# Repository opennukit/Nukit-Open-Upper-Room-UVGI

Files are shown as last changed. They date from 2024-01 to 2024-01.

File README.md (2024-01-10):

# About Nukit Open Upper Room UVGI
Nukit Open Upper-Room UVGI (Ultraviolet Germicidal Irradiation) fixtures are Open Hardware devices for researching and developing localized Upper-Room UVGI solutions. They are not a DIY project and should only be used with UVC lights by qualified professionals. If you would like to learn about Upper-Room UVGI you can use them with safe, readily available white lights and a lux meter. 

Qualified professionals will need a UVC meter that measures 254nm to 0.01 mW/cm2 resolution, a protective face shield that has UV blocking characteristics verified by that UVC meter, long sleeves, and lightweight gloves.

If you attempt to deploy or research UVGI without the above equipment, you will likely become a news story that further harms this potentially life-saving technology. 

[Geneseo faculty say an experiment using ultraviolet light to kill COVID-19 damaged their eyes](https://www.wxxinews.org/local-news/2022-04-14/geneseo-faculty-say-uv-c-light-to-target-covid-damaged-their-eyes)

[Doctors warn about eye damage from UV lights to kill the coronavirus](https://www.nbcnews.com/health/health-news/doctors-warn-about-eye-damage-uv-lights-kill-coronavirus-n1249009)

[Bored Ape creator says UV lights at ApeFest burned attendees’ eyes and skin](https://arstechnica.com/health/2023/11/bored-ape-creator-says-uv-lights-at-apefest-burned-attendees-eyes-and-skin/)

**General Guidelines**
---
There are reference Nukit Open Upper-Room UVGI fixtures available for hand tools, lasercutting, 3D printing, and sheet metal fabrication. All are designed to be adapted to local materials and conditions by local engineers and researchers. [Read more about the project here.](https://github.com/opennukit/Nukit-Open-Upper-Room-UVGI/blob/e78abfc1034ac28526194f0c7dd7b21da4218601/Nukit%20Open%20Upper%20Room%20UVGI%20Project%20Description/OSH-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)

For an excellent overview of Upper-Room UVGI, see Joey Fox's article [Intro to Upper-Room UVGI](https://itsairborne.com/intro-to-upper-room-uvgi-a36e00862c04)

There are videos featuring the fabrication and installation of Open Upper-Room UVGI [here](https://youtu.be/QSnUce9xdNo) and [here](https://youtu.be/VVzKQwjtzhc). However, once again, this is not a DIY project, and non-professional experimentation should be done with safe, white light.

The following two guides should be considered a prerequisite for any Open Upper-Room UVGI fabrication, installation, or experimentation.

[Guidelines for the Application of Upper-Room Ultraviolet Germicidal Irradiation for Preventing Transmission of Airborne Contagion—Part I- Basic Principles](https://www.mediafire.com/file/c3c6aij5ctm65wk/Guidelines_for_the_Application_of_Upper-Room_Ultraviolet_Germicidal_Irradiation_for_Preventing_Transmission_of_Airborn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)

[Guidelines for the Application of Upper-Room Ultraviolet Germicidal Irradiation for Preventing Transmission of Airborne Contagion—Part II- Design and Operation Guidance](https://www.mediafire.com/file/8tyhdqi13e3368i/Guidelines_for_the_Application_of_Upper-Room_Ultraviolet_Germicidal_Irradiation_for_Preventing_Transmission_of_Airborn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)

(Sorry for the MediaFire link, please let us know if you are willing to host PDFs with potential DMCA issues on a private server)

This project was funded by a grant from Vitalik Buterin's Balvi Fund.

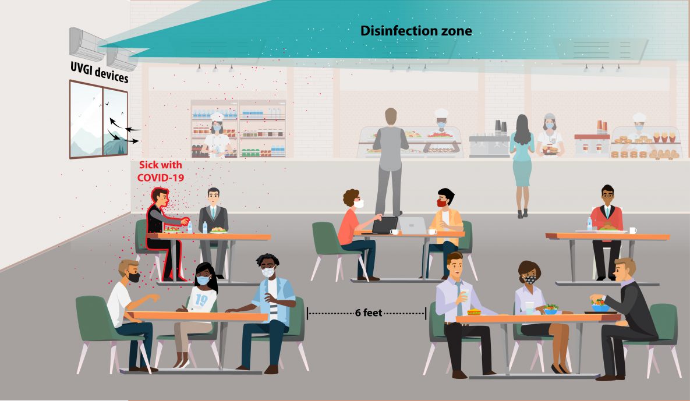
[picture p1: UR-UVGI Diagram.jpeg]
Upper-Room UVGI Diagram


**License**
---
All Nukit Open Upper Room UVGI fixtures are released under GPL-3. 
https://www.gnu.org/licenses/gpl-3.0.en.html

TLDR;
(For our purposes, “software” refers to the digital files used to make Nukit Open Upper Room UVGI fixtures)

1. Anyone can copy, modify and distribute this software.
2. You have to include the license and copyright notice with each and every distribution.
3. You can use this software privately.
4. You can use this software for commercial purposes.
5. If you dare build your business solely from this code, you risk open-sourcing the whole code base.
6. If you modify it, you have to indicate changes made to the code.
7. Any modifications of this code base MUST be distributed with the same license, GPLv3.
8. This software is provided without warranty.
9. The software author or license can not be held liable for any damages inflicted by the software.

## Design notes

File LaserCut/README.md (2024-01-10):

# Laser-Cut Nukit Open Upper-Room UVGI

Laser-Cut Nukit Open Upper-Room UVGI fixtures are designed to be made on laser diode or CO2 laser cutters, anywhere in the world, from local materials. They cost a fraction of the price of commercial UR-UVGI fixtures and can be customized to suit local conditions. They do, however, require careful installation by trained technicians. Once that's done, they are extremely effective, safe, and inexpensive to operate.

**Pendent Style- Wood**
---
This is a very powerful, very low-cost mitigation tool that, with appropriate training, can be rapidly deployed in disaster areas, field hospitals, refugee camps, commandeered auditoriums, and gymnasiums. Any place that is large, crowded, has high ceilings and is high risk for aerosol transmission. 

When cut out of 2mm plywood the cost is about 8USD. Combined with an Ikea [STRÅLA](https://www.ikea.com/us/en/p/strala-cord-set-white-90371505/) (5USD) or [HEMMA](https://www.ikea.com/us/en/p/hemma-cord-set-white-50386580/) (10USD) and a UVC CFL bulb there is very little light leakage below the fixture. The irradiation field is 360° and 3° down (see diagram). As such, very little light is wasted, and they are extremely efficient.

At and above ahorizontal plane the output level is approximately:  
16μW/cm2 @ 1m  
7μW/cm2 @ 1.5m  
4μW/cm2 @ 2m

Diagram of safe versus germicidal zones:
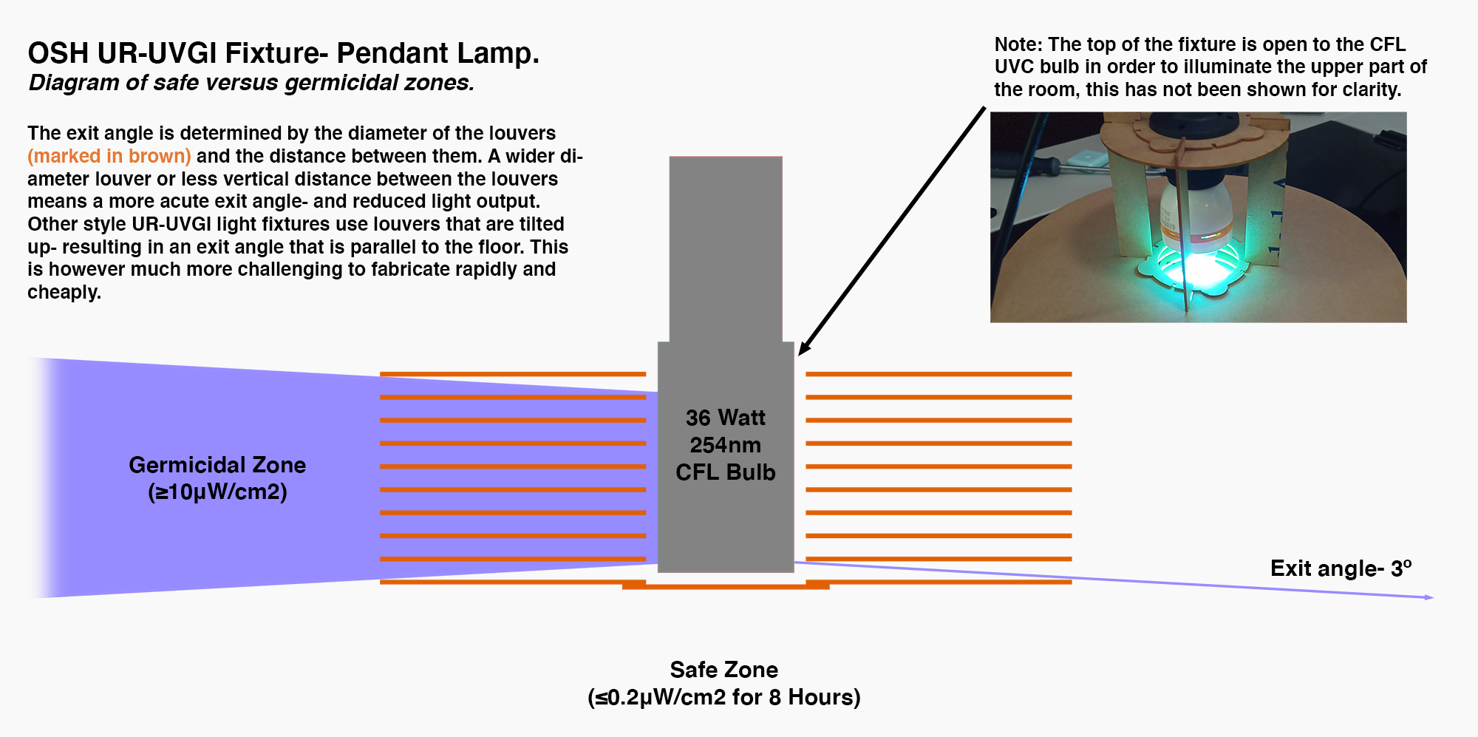
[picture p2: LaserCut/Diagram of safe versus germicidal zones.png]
Diagram of safe versus germicidal zones


[This version is the best one to start with](https://github.com/opennukit/Nukit-Open-Upper-Room-UVGI/tree/main/LaserCut/Nukit%20Open%20Upper%20Room%20UVGI%20Pendent%20Fixture/Nukit%20Open%20Upper%20Room%20UVGI%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), as it is nested and shippable. Secures with zip-ties, forming an extremely robust solid block that stacks and stands up well to rough handling. There is a somewhat heavier [1/8th inch version here](https://github.com/opennukit/Nukit-Open-Upper-Room-UVGI/tree/main/LaserCut/Nukit%20Open%20Upper%20Room%20UVGI%20Pendent%20Fixture/Nukit%20Open%20Upper%20Room%20UVGI%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) that will require more care in hanging but is easier to make in North America.

The assembly instructions are [here](https://github.com/opennukit/Nukit-Open-Upper-Room-UVGI/blob/main/LaserCut/Nukit%20Open%20Upper%20Room%20UVGI%20Pendent%20Fixture/Nukit%20Open%20Upper%20Room%20UVGI%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)

Note- coiled E27 UVC CFL bulbs have become difficult to find, but this fixture design can accommodate the more easy-to-source [long and straight E27 UVC CFL bulbs](https://www.amazon.com/coospider-repta-Sanitizer-Germicidal-Replacement-Disinfection/dp/B0CG39F65Z/) simply by adding additional layers of louvers. (NOTE: DO NOT USE UVC LAMPS UNLESS YOU ARE A QUALIFIED PROFESSIONAL WITH A UVC METER- USE WHITE LIGHTS FOR TESTING)

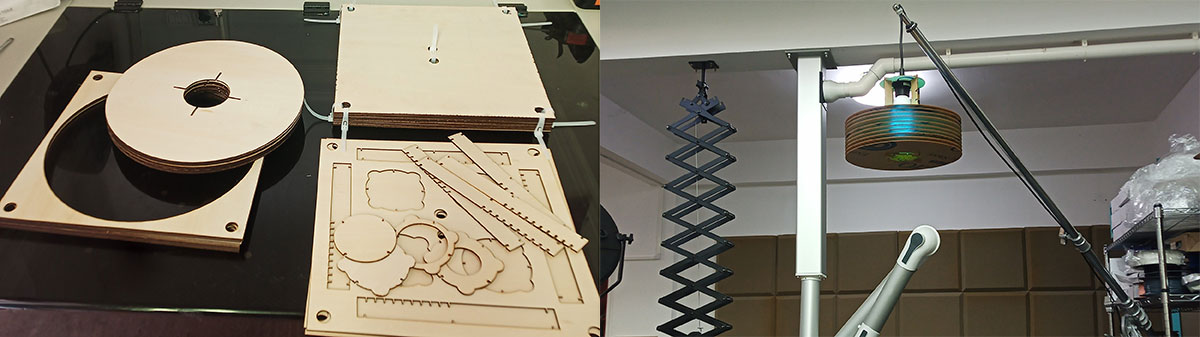
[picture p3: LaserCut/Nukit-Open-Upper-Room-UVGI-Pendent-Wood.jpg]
Laser-Cut Nukit Open Upper Room UVGI Pendent Wood


**Wall-Mount Style- Wood**
---
This style has a more tightly controlled output than the above pendent-style lamp, making it much less powerful but also far easier and safer to install. Using aluminum tape inside the box will greatly improve its efficiency. It uses [M5 threaded rod](https://www.mcmaster.com/products/threaded-rods/thread-size~m5/metric-18-8-stainless-steel-threaded-rods/), [M5 thumb nuts](https://www.amazon.com/uxcell-Knurled-Thumb-Nuts-Stainless/dp/B07WMQL8VX) (can be substituted for imperial sizes depending on local cost and availability), and two [6W T5 mercury vapor UVC lamps](https://www.amazon.com/UV-Sanitizer-253-7nm-wavelength-Bathroom/dp/B0B5CV9PB5). The fixture can easily be extended to accommodate any length of T5 fixture up to 150cm. (NOTE: DO NOT USE UVC LAMPS UNLESS YOU ARE A QUALIFIED PROFESSIONAL WITH A UVC METER- USE WHITE LIGHTS FOR TESTING)

[This version is the best one to start with](https://github.com/opennukit/Nukit-Open-Upper-Room-UVGI/tree/main/LaserCut/Nukit%20Open%20Upper%20Room%20UVGI%20Wall%20Fixture/Nukit%20Open%20Upper%20Room%20UVGI%20(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), as it is nested and shippable. Secures with zip-ties, forming an extremely robust solid block that stacks and stands up well to rough handling. 

The assembly instructions are [here](https://github.com/opennukit/Nukit-Open-Upper-Room-UVGI/tree/main/LaserCut/Nukit%20Open%20Upper%20Room%20UVGI%20Wall%20Fixture/Nukit%20Open%20Upper%20Room%20UVGI%20(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)

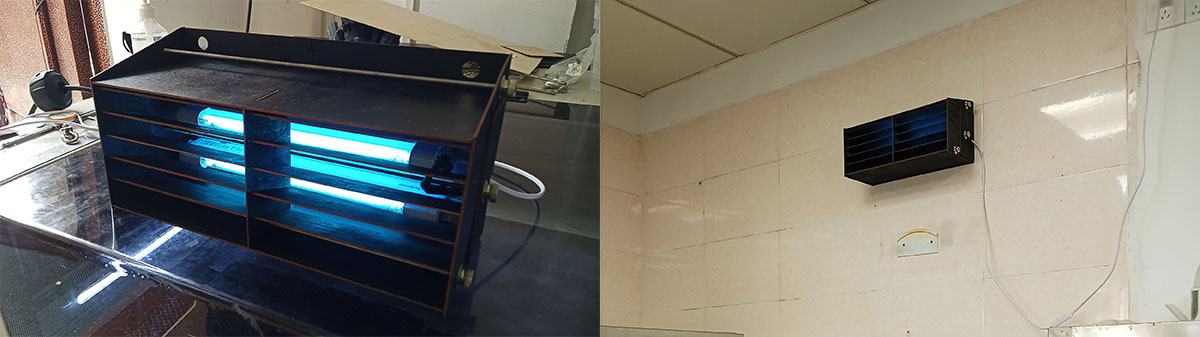
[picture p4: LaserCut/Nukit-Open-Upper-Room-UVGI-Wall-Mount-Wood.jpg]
Laser-Cut Nukit Open Upper Room UVGI Wall-Mount-Wood


**Wall-Mount Style- Metal**
---
An all-metal version of the Nukit Open Upper Room UVGI Wall-Mount fixture. It is designed for local manufacturing and commercial deployment in any country. It can be made in most sheet metal shops equipped with laser or waterjet cutters for a fraction of the cost of importing UR-UVGI devices from overseas.

[You can download the plans here.](https://github.com/opennukit/Nukit-Open-Upper-Room-UVGI/tree/main/LaserCut/Nukit%20Open%20Upper%20Room%20UVGI%20Wall%20Fixture/Nukit%20Open%20Upper%20Room%20UVGI%20W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)

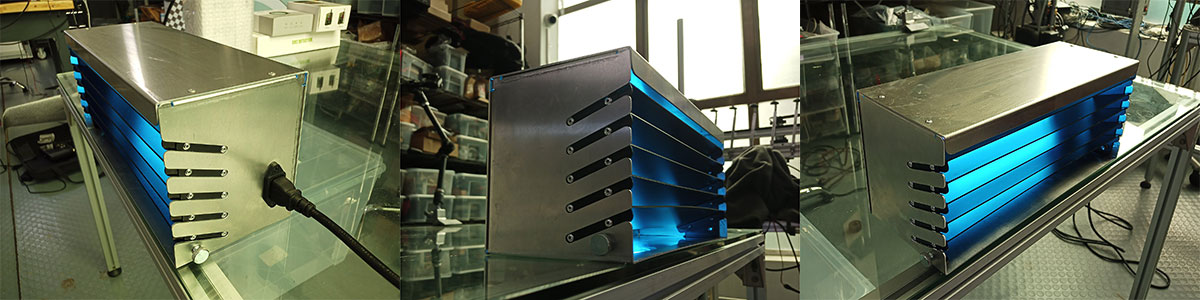
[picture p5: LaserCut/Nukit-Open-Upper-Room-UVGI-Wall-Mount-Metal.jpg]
Laser-Cut Nukit Open Upper Room UVGI Wall-Mount-Metal


**License**
---
All Nukit Open Air Purifiers are released under GPL-3. 
https://www.gnu.org/licenses/gpl-3.0.en.html

TLDR;
(For our purposes, “software” refers to the digital files used to make Nukit Open Air Purifiers)

1. Anyone can copy, modify and distribute this software.
2. You have to include the license and copyright notice with each and every distribution.
3. You can use this software privately.
4. You can use this software for commercial purposes.
5. If you dare build your business solely from this code, you risk open-sourcing the whole code base.
6. If you modify it, you have to indicate changes made to the code.
7. Any modifications of this code base MUST be distributed with the same license, GPLv3.
8. This software is provided without warranty.
9. The software author or license can not be held liable for any damages inflicted by the software.

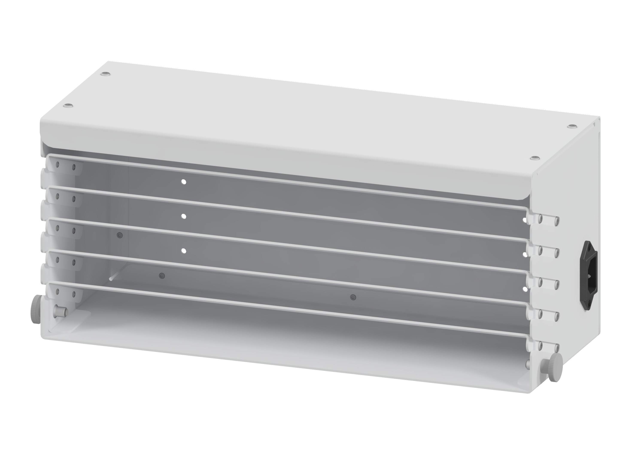
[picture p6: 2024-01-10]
LaserCut/Nukit Open Upper Room UVGI Wall Fixture/Nukit Open Upper Room UVGI Wall Fixture 1.6mm Aluminum/Nukit Open Upper Room UVGI Wall Fixture 1.6mm Aluminum v1.png

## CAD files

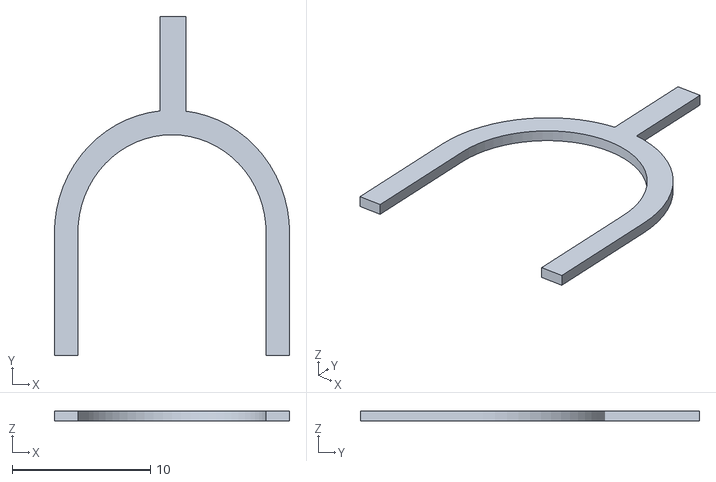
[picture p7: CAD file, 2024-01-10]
LaserCut/Nukit Open Upper Room UVGI Pendent Fixture/UVGI-Assembly-Tool.stl
17.0 x 24.5 x 0.75

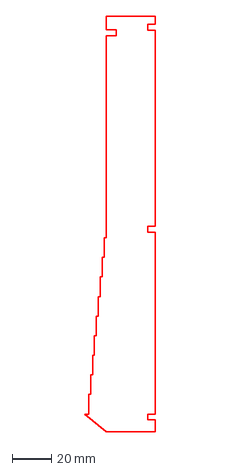
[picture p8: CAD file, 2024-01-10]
LaserCut/Nukit Open Upper Room UVGI Pendent Fixture/Nukit Open Upper Room UVGI Pendent Variants/Nukit Open Upper Room UVGI Pendent Fixture v1 revision c/Nukit Open Upper Room UVGI Pendent Fixture v1 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
36.0 x 212.0 mm

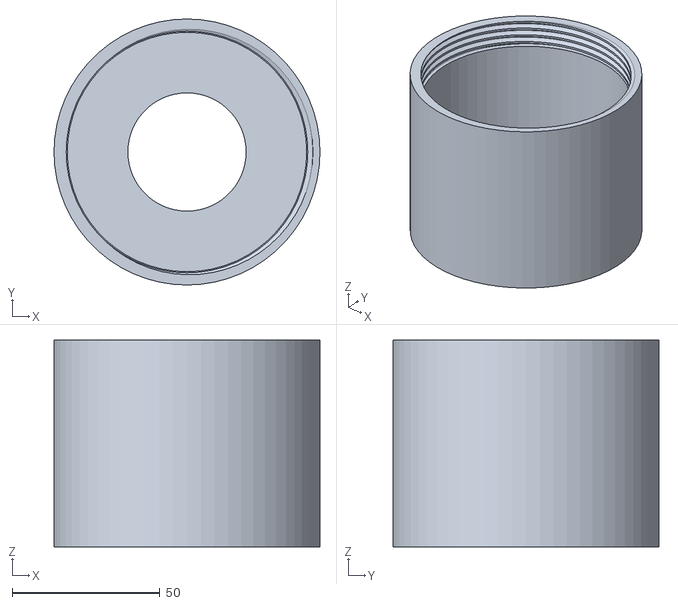
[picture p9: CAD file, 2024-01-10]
3D Printed/UVGI-3DP FDM PETG 220x220x220 Cap.stl
90.0 x 90.0 x 70.0

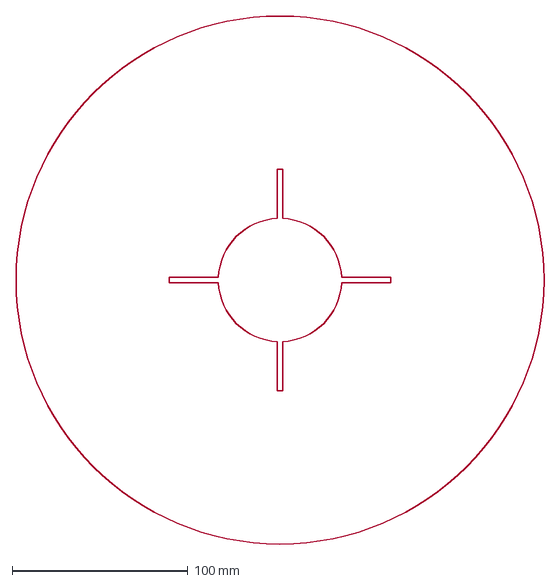
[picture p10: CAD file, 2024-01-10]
LaserCut/Nukit Open Upper Room UVGI Pendent Fixture/Nukit Open Upper Room UVGI Pendent Variants/Nukit Open Upper Room UVGI Pendent Fixture v1 revision c/Nukit Open Upper Room UVGI Pendent Fixture v1 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
300.0 x 300.0 mm

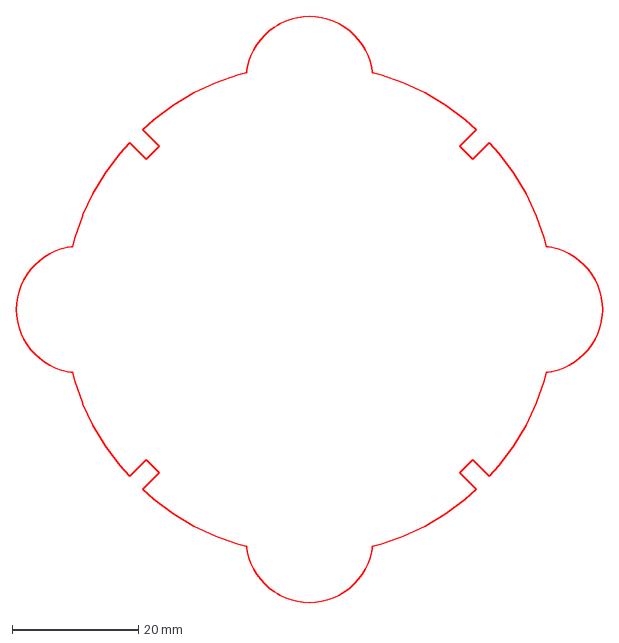
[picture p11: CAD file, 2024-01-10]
LaserCut/Nukit Open Upper Room UVGI Pendent Fixture/Nukit Open Upper Room UVGI Pendent Variants/Nukit Open Upper Room UVGI Pendent Fixture v1 revision c/Nukit Open Upper Room UVGI Pendent Fixture v1 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
92.9 x 92.9 mm

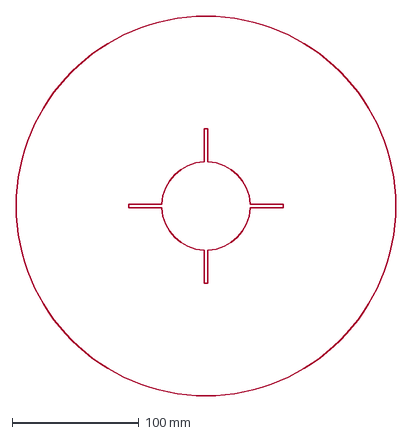
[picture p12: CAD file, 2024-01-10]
LaserCut/Nukit Open Upper Room UVGI Pendent Fixture/Nukit Open Upper Room UVGI Pendent Variants/Nukit Open Upper Room UVGI Pendent Fixture v1 revision c/Nukit Open Upper Room UVGI Pendent Fixture v1 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
300.0 x 300.0 mm

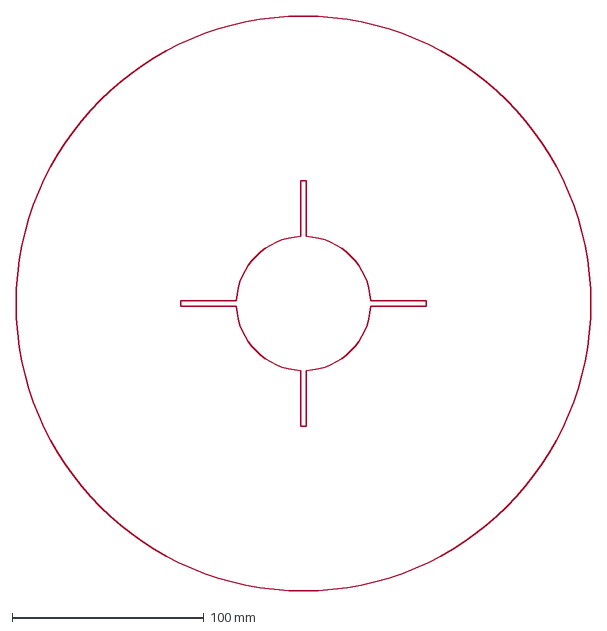
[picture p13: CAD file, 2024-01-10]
LaserCut/Nukit Open Upper Room UVGI Pendent Fixture/Nukit Open Upper Room UVGI Pendent Variants/Nukit Open Upper Room UVGI Pendent Fixture v1 revision c/Nukit Open Upper Room UVGI Pendent Fixture v1 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
300.0 x 300.0 mm

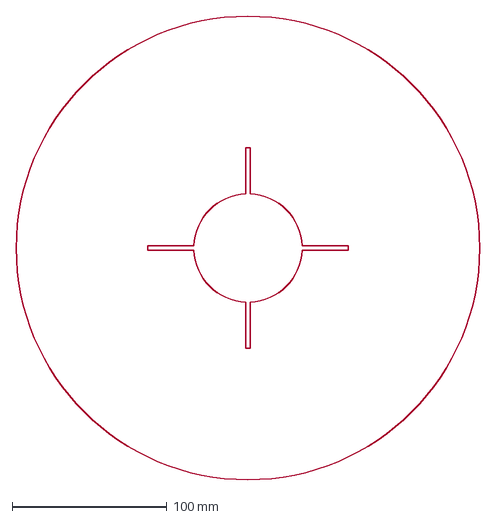
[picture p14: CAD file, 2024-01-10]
LaserCut/Nukit Open Upper Room UVGI Pendent Fixture/Nukit Open Upper Room UVGI Pendent Variants/Nukit Open Upper Room UVGI Pendent Fixture v1 revision c/Nukit Open Upper Room UVGI Pendent Fixture v1 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
300.0 x 300.0 mm

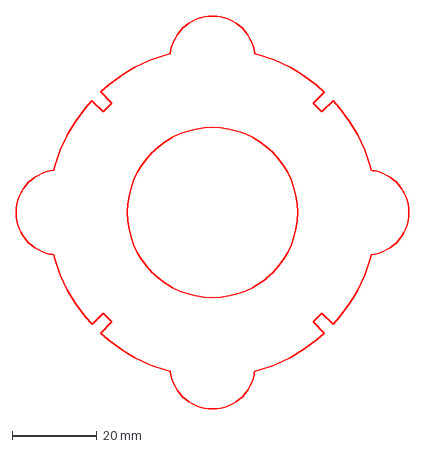
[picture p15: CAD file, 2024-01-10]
LaserCut/Nukit Open Upper Room UVGI Pendent Fixture/Nukit Open Upper Room UVGI Pendent Variants/Nukit Open Upper Room UVGI Pendent Fixture v1 revision c/Nukit Open Upper Room UVGI Pendent Fixture v1 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
92.9 x 92.9 mm

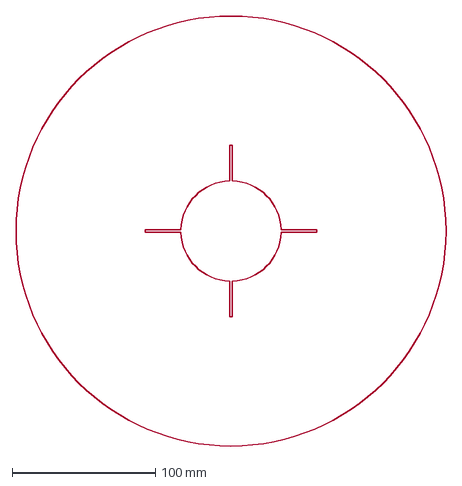
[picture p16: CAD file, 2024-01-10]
LaserCut/Nukit Open Upper Room UVGI Pendent Fixture/Nukit Open Upper Room UVGI Pendent Variants/Nukit Open Upper Room UVGI Pendent Fixture v1 revision c/Nukit Open Upper Room UVGI Pendent Fixture v1 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
300.0 x 300.0 mm

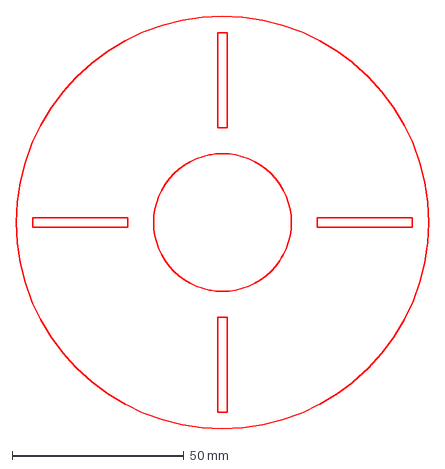
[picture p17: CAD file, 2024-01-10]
LaserCut/Nukit Open Upper Room UVGI Pendent Fixture/Nukit Open Upper Room UVGI Pendent Variants/Nukit Open Upper Room UVGI Pendent Fixture v1 revision c/Nukit Open Upper Room UVGI Pendent Fixture v1 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
120.0 x 120.0 mm

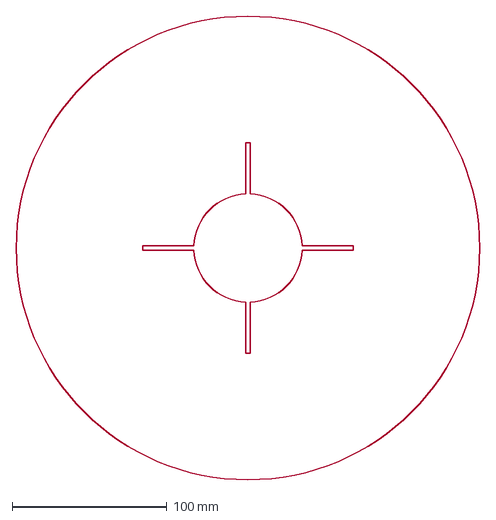
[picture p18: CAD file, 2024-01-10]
LaserCut/Nukit Open Upper Room UVGI Pendent Fixture/Nukit Open Upper Room UVGI Pendent Variants/Nukit Open Upper Room UVGI Pendent Fixture v1 revision c/Nukit Open Upper Room UVGI Pendent Fixture v1 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
300.0 x 300.0 mm

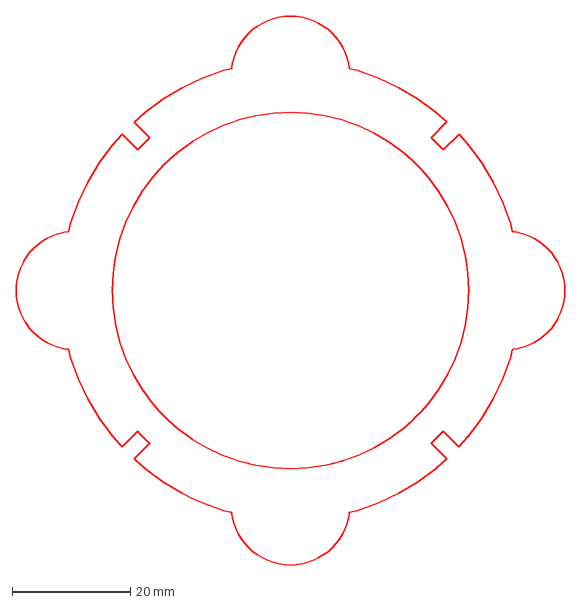
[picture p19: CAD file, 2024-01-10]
LaserCut/Nukit Open Upper Room UVGI Pendent Fixture/Nukit Open Upper Room UVGI Pendent Variants/Nukit Open Upper Room UVGI Pendent Fixture v1 revision c/Nukit Open Upper Room UVGI Pendent Fixture v1 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
92.9 x 92.9 mm

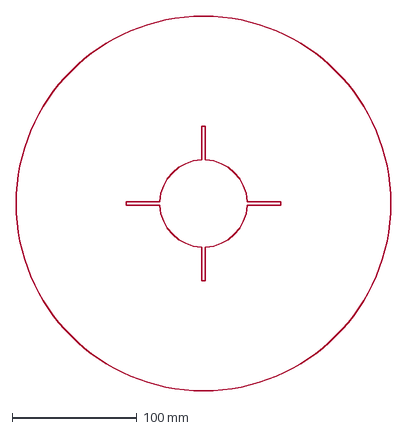
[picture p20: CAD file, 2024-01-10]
LaserCut/Nukit Open Upper Room UVGI Pendent Fixture/Nukit Open Upper Room UVGI Pendent Variants/Nukit Open Upper Room UVGI Pendent Fixture v1 revision c/Nukit Open Upper Room UVGI Pendent Fixture v1 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
300.0 x 300.0 mm

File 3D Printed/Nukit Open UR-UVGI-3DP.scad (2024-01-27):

/* [Model Options] */

Print_Part = "shade"; // ["shade","cap","assembly"]

/* [UV Lampshade] */
Shade_Height = 120;   // [50:400]
Shade_Diameter = 120; // [50:400]
Shade_Bore = 70;      // [20:100]
Base_Height = 2;      // [0:5]

/* [Light Ports] */
Top_Wedge = true; 
Port_X_Count = 44;  // [0:60]
Port_Y_Count = 12;   // [0:30]
Port_Wall = 0.8;      // [0:0.1:5]
Port_Segments = 100; // [5:200]
Port_Angle = 0;     // [-30:45]

/* [Screw Thread] */
Thread_Height = 10;      // [5:20]
Thread_Pitch = 3;        // [1:0.1:5]
Thread_Angle = 30;	    // [20:45]
Thread_Resolution = 60; // [60,120,180]

/* [Screw Cap] */
Cap_Height = 70;        // [10:100]
Cap_Bore = 40;          // [0:100]
Cap_Hole_Count   = 0;   // [0:20]
Cap_Hole_Offset  = 30;  // [0:0.1:100]
Cap_Hole_Size = 4;      // [1:0.1:40]
Cap_Thread_Tolerance = 0.3; // [0:0.1:0.5]

/* [Assembly] */
Cutaway = false;


/* [Hidden] */
Thread_Diameter = Shade_Bore + 15;

use <quickthread.scad> 

if(Print_Part=="shade") {
	lightshade();
} else if(Print_Part=="cap") {
	translate([0,0,Cap_Height]) rotate([180,0,0]) lightshade_cap();
} else if(Print_Part=="dev") {
	if(1) helix();
	if(0) helix_wedge(segments=10);
} else if(Print_Part=="assembly") {
	if(1) difference() {
		color("gold") lightshade();
		if(Cutaway) color("red") translate([0,0,Base_Height+10+0.001]) cube([100,100,120]);
	}

	if(1) translate([0,0,Shade_Height + 0.0]) difference() {
		color("gold") lightshade_cap();
		if(Cutaway) color("red") translate([0,0,-0.001]) cube([Shade_Diameter/2,Shade_Diameter/2,120]);
	}
}


function circle_p(theta) = [cos(theta),sin(theta),0];

module helix(or=50,ir=20,h=40,wall=2,wrap=0.2,segments=50) {
	rz = (or-ir)*sin(Port_Angle); // radial height change
	base = (Port_Angle<0) ? rz : 0;
	zh = h + (Top_Wedge ? abs(base) : abs(rz));
	ai = 360*wrap/segments;
	zi = zh/segments;
	points = [for(i=[0:segments]) each [ 
		// commpute the four points of this segment
		ir*circle_p(i*ai) + wall/2*circle_p(i*ai+90) + [0,0,base+i*zi-rz],
		ir*circle_p(i*ai) + wall/2*circle_p(i*ai-90) + [0,0,base+i*zi-rz],
		or*circle_p(i*ai) + wall/2*circle_p(i*ai-90) + [0,0,base+i*zi],
		or*circle_p(i*ai) + wall/2*circle_p(i*ai+90) + [0,0,base+i*zi]
	]];
	//echo(points);
	bottom_face = [0,1,2,3];
	top_face = [3,2,1,0] + (segments)*[4,4,4,4];
	connect_faces = [
		[1,0, 4,5],
		// [2,1, 5,6],
		[2,1,5], [2,5,6],
		[3,2, 6,7],
		// [0,3, 7,4],
		[0,3,4], [3,7,4]
	];
	faces = [ 
		bottom_face,
		for(i=[0:segments-1]) for(v = connect_faces) v + i*[4,4,4,4],
		top_face 
	];
	//echo(faces);
	polyhedron(points = points, faces = faces, convexity=4);
}


module helix_wedge(or=50,ir=20,h=40,wall=2,wrap=0.1,segments=50) {
	ai = 360*wrap/segments;
	zi = h/segments;
	zri = (or-ir)*sin(Port_Angle);
	points = [for(i=[0:segments]) each let(w = wall/2 * (segments-i)/segments, ratio=1-i/(segments) ) [ 
		// commpute the four points of this segment
		ir*circle_p(i*ai)  + w*circle_p(i*ai+90)  + [0,0,i*zi-zri],
		ir*circle_p(-i*ai) + w*circle_p(-i*ai-90) + [0,0,i*zi-zri],
		or*circle_p(-i*ai) + w*circle_p(-i*ai-90) + [0,0,i*zi],
		or*circle_p(i*ai)  + w*circle_p(i*ai+90)  + [0,0,i*zi]
	]];
	//echo(points);
	bottom_face = [0,1,2,3];
	top_face = [3,2,1,0] + (segments)*[4,4,4,4];
	connect_faces = [
		[1,0, 4,5],
		// [2,1, 5,6],
		[2,1,5], [2,5,6],
		[3,2, 6,7],
		// [0,3, 7,4],
		[0,3,4], [3,7,4]
	];
	faces = [ 
		bottom_face,
		for(i=[0:segments-1]) for(v = connect_faces) v + i*[4,4,4,4],
		top_face 
	];
	//echo(faces);
	if(Port_Angle<0) {
		hull() polyhedron(points = points, faces = faces, convexity=4);
	} else {
		polyhedron(points = points, faces = faces, convexity=4);
	}
}

module lightshade() {
	// do we need the top wedge, either because requested or because we have a positive port angle
	need_wedge = Top_Wedge; //  || (Port_Angle>0) ? true : false;
	cap_fn = need_wedge ? Port_X_Count : 180;
	// start with a solid base
	linear_extrude(height=Base_Height, convexity=2) {
		circle(d=Shade_Diameter+1.001, $fn=180);
	}
	intersection() {
		// confine to the cylinder
		cylinder(d=Shade_Diameter+10, h=Shade_Height, $fn=Port_X_Count*2);
		union() {
			// helixes
			hh = (Shade_Height - Base_Height * 2) / (Port_Y_Count + (need_wedge ? 0.5 : 0));
			for(j=[0:Port_X_Count-1]) translate([0,0,Base_Height]) {
				rotate(360/Port_X_Count*j) {
					w = 1/Port_X_Count * Port_Y_Count;
					h = hh * Port_Y_Count;
					helix(or=Shade_Diameter/2, ir=Shade_Bore/2, h=h, wall=Port_Wall, wrap=w,  segments=Port_Segments);
					helix(or=Shade_Diameter/2, ir=Shade_Bore/2, h=h, wall=Port_Wall, wrap=-w, segments=Port_Segments);
				}
			}
			// top wedges
			if(need_wedge) {
				for(j=[0:Port_X_Count-1]) translate([0,0,Shade_Height-Base_Height-hh/2]) {
					rotate(360/Port_X_Count*j) {
						w = 1/Port_X_Count;
						h = hh / 2;
						helix_wedge(or=Shade_Diameter/2, ir=Shade_Bore/2, h=h, wall=Port_Wall, wrap=w/2,  segments=floor(Port_Segments/Port_Y_Count/2));
					}
				}
			}
		}
	}
	// cap with bore hole
	translate([0,0,Shade_Height-Base_Height-0.001]) rotate(need_wedge ? 180/Port_X_Count : 0 ) {
		linear_extrude(height=Base_Height, convexity=2) difference() {
			circle(d=Shade_Diameter, $fn=cap_fn);
			circle(d=Shade_Bore, $fn=cap_fn);
		}
		zri = (Shade_Diameter-Shade_Bore)/2*sin(Port_Angle);
		mirror([0,0,1]) difference() {
			cylinder(d1=Shade_Diameter, d2=Shade_Bore, h=zri, $fn=cap_fn);
			translate([0,0,-1]) cylinder(d=Shade_Bore, h=zri+2, $fn=cap_fn);
		}
	}
	// thread on top
	translate([0,0,Shade_Height-0.002]) difference() {
		isoThread(d=Thread_Diameter, h=Thread_Height, pitch=Thread_Pitch,angle=Thread_Angle,internal=false,$fn=Thread_Resolution);
		rotate(Top_Wedge ? 180/Port_X_Count : 0 ) translate([0,0,-1]) cylinder(d=Shade_Bore, h=Thread_Height+2, $fn=cap_fn);
	}
}

module lightshade_cap(h=Cap_Height,base_h=3) {
	difference() {
		translate([0,0,0.001]) cylinder(d=Thread_Diameter+6, h=h, $fn=Thread_Resolution);
		union() {
			// thread 
			isoThread(d=Thread_Diameter+Cap_Thread_Tolerance*2, h=Thread_Height+1, pitch=Thread_Pitch,angle=Thread_Angle,internal=true,$fn=Thread_Resolution);
			// above-thread space
			translate([0,0,Thread_Height+1-0.01]) cylinder(d=max(Cap_Bore, Thread_Diameter-4), h=h-Thread_Height-base_h-1, $fn=Thread_Resolution);
			// cap bore
			if(Cap_Bore) cylinder(d=Cap_Bore, h=h+0.01, $fn=Thread_Resolution);
			// cap holes
			if(Cap_Hole_Count) {
				for(i=[0:Cap_Hole_Count-1]) rotate(i*360/Cap_Hole_Count) 
					translate([Cap_Hole_Offset,0,0]) cylinder(d=Cap_Hole_Size, h=h+0.01, $fn=24);
			}
		}
	}
}

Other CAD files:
LaserCut/Nukit Open Upper Room UVGI Pendent Fixture/Nukit Open Upper Room UVGI Pendent Variants/Nukit Open Upper Room UVGI Pendent Fixture v1 revision c/Nukit Open Upper Room UVGI Pendent Fixture v1 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
LaserCut/Nukit Open Upper Room UVGI Pendent Fixture/Nukit Open Upper Room UVGI Pendent Variants/Nukit Open Upper Room UVGI Pendent Fixture v1 revision c/Nukit Open Upper Room UVGI Pendent Fixture v1 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
LaserCut/Nukit Open Upper Room UVGI Pendent Fixture/Nukit Open Upper Room UVGI Pendent Variants/Nukit Open Upper Room UVGI Pendent Fixture v1 revision c/Nukit Open Upper Room UVGI Pendent Fixture v1 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
3D Printed/quickthread.scad

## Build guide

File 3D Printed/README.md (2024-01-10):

# 3D Printed Nukit Open Upper Room UVGI

This is a pendant-style UR-UVGI fixture that can be 3D printed in any size on almost any FDM or resin printer. STL samples are included, but for best results, use the parametric OpenSCAD model to build a fixture to suit your specific requirements and print bed size. Due to heat from the mercury vapor lamp, FDM prints should not be done with PLA but instead with PETG or similar higher temperature filament.

OpenSCAD is a code-based CAD modeling program. The attached scad files can easily be edited using the sliders on the right and then exported as an STL for 3D printing. Be sure to check the angle of illumination for each modified design and ensure that it fits the room.

[Download OpenSCAD](http://openscad.org).

[Basic OpenSCAD tutorial](https://cubehero.com/2013/11/19/know-only-10-things-to-be-dangerous-in-openscad/)

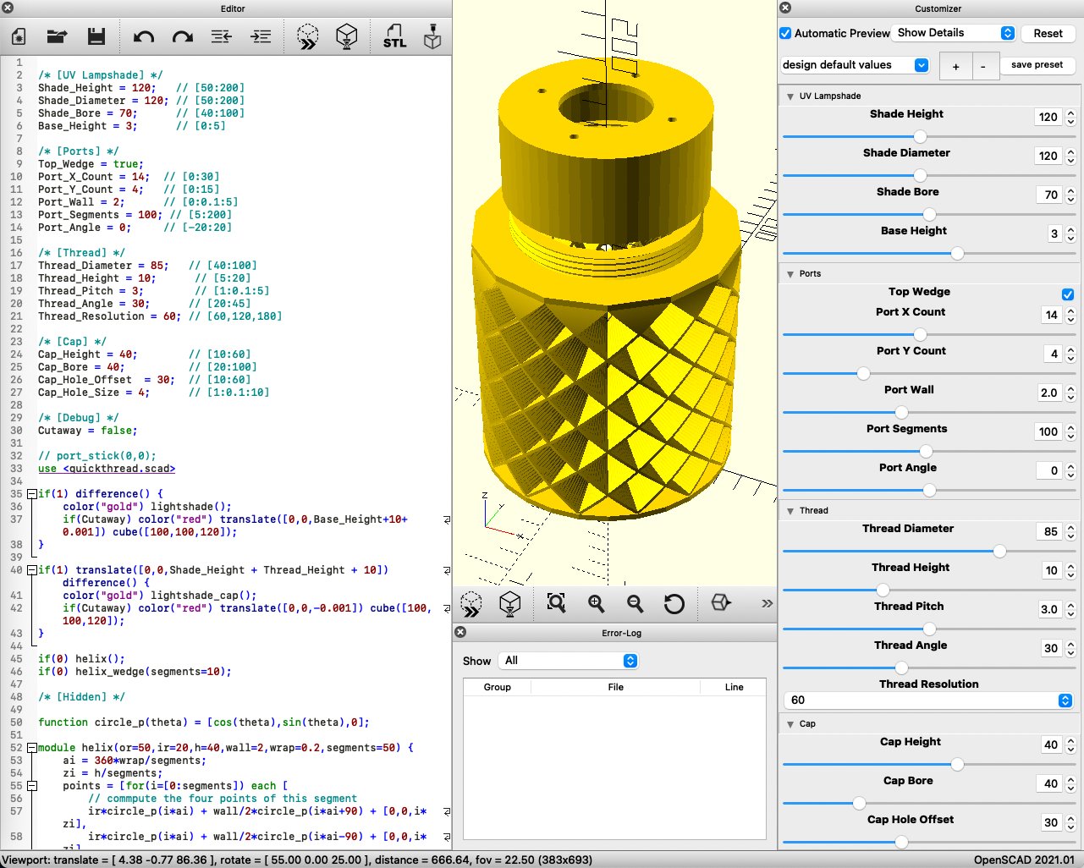
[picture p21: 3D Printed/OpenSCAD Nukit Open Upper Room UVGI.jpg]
OpenSCAD Nukit Open Upper Room UVGI


**License**
---
All Nukit Open Air Purifiers are released under GPL-3. 
https://www.gnu.org/licenses/gpl-3.0.en.html

TLDR;
(For our purposes, “software” refers to the digital files used to make Nukit Open Air Purifiers)

1. Anyone can copy, modify and distribute this software.
2. You have to include the license and copyright notice with each and every distribution.
3. You can use this software privately.
4. You can use this software for commercial purposes.
5. If you dare build your business solely from this code, you risk open-sourcing the whole code base.
6. If you modify it, you have to indicate changes made to the code.
7. Any modifications of this code base MUST be distributed with the same license, GPLv3.
8. This software is provided without warranty.
9. The software author or license can not be held liable for any damages inflicted by the software.

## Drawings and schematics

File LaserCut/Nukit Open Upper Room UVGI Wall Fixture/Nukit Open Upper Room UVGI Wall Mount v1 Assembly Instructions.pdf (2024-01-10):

# Wall Fixture

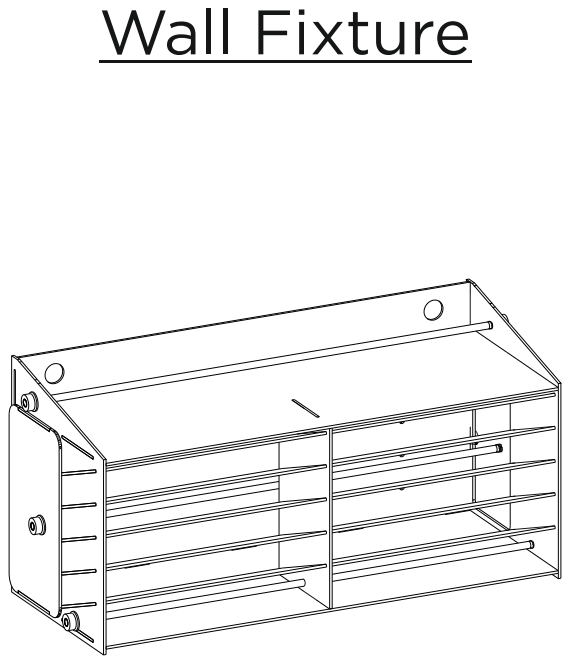
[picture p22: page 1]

1x

2x

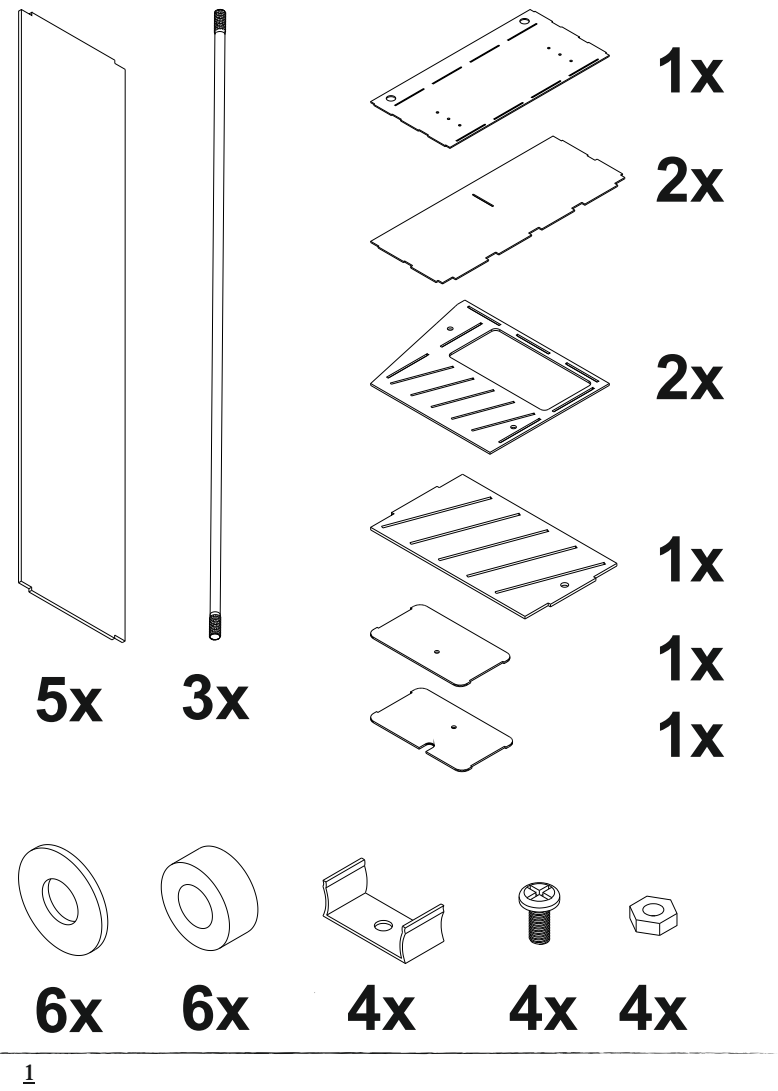
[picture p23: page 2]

1

# step .3

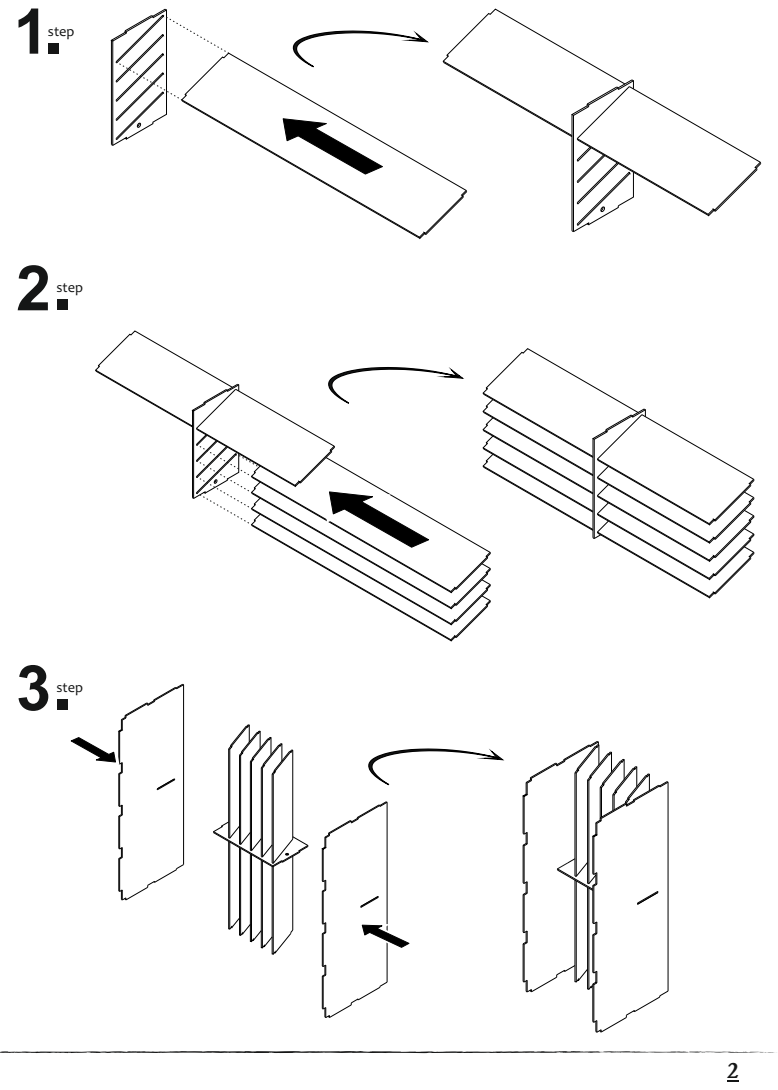
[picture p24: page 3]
step .

4

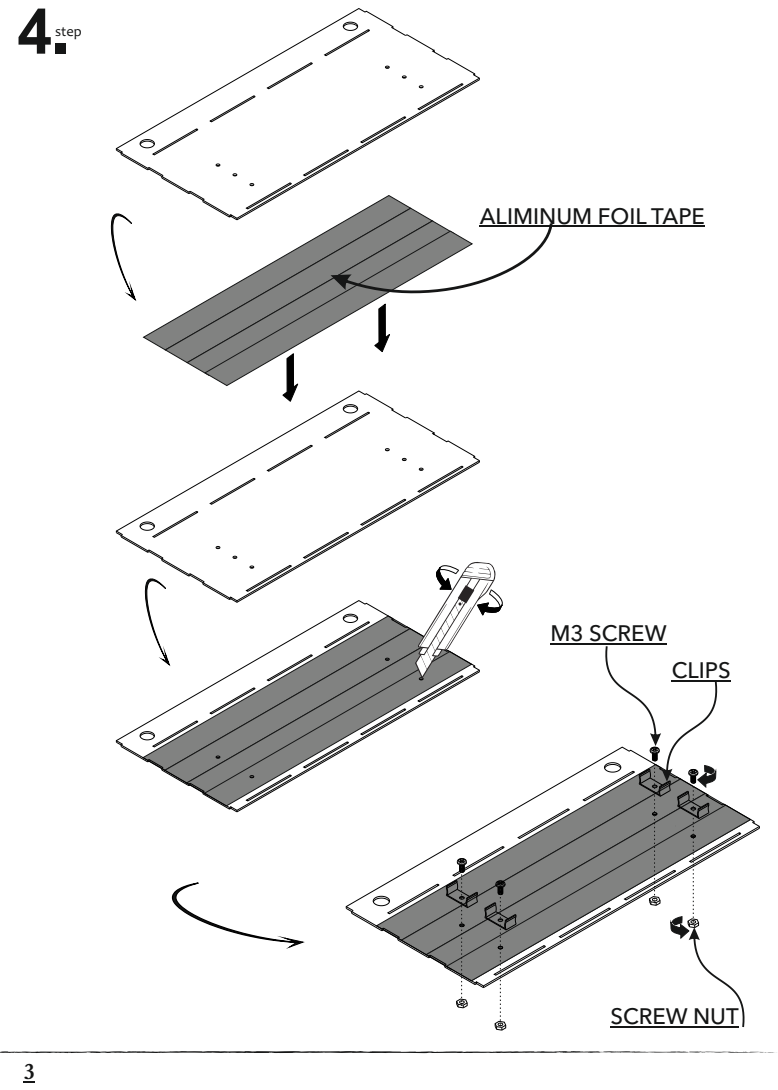
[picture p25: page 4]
CLIPS; M3 SCREW; SCREW NUT; step

ALIMINUM FOIL TAPE

5

step .

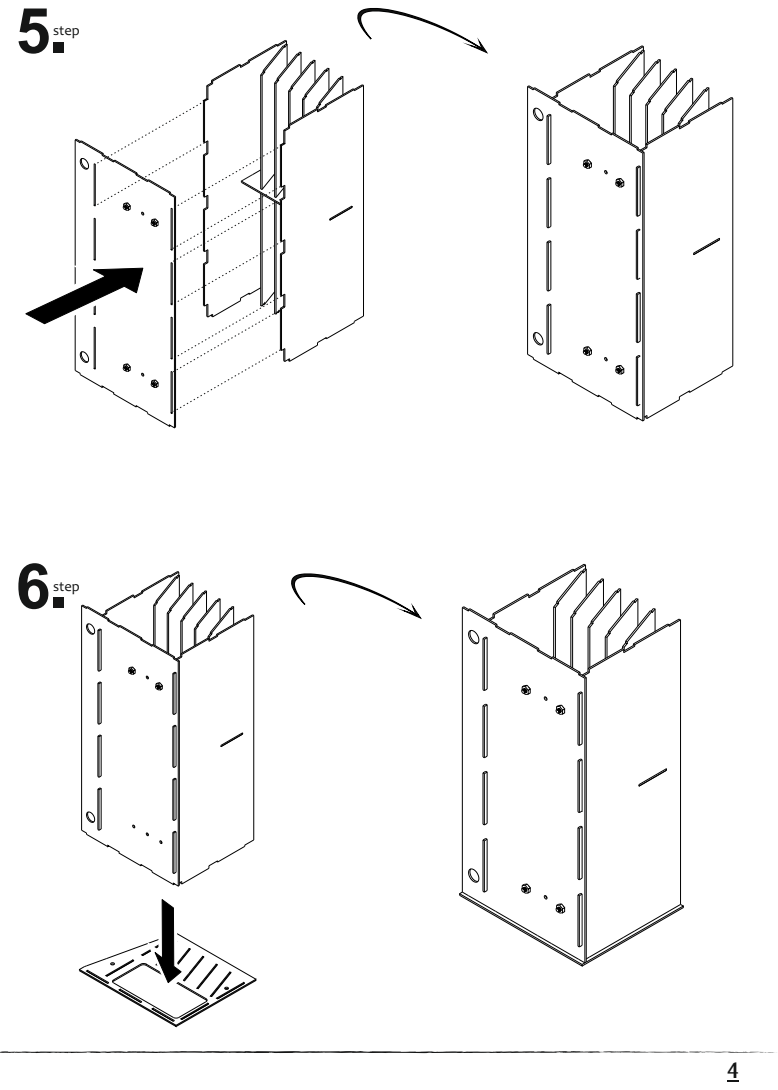
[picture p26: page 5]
step .

7

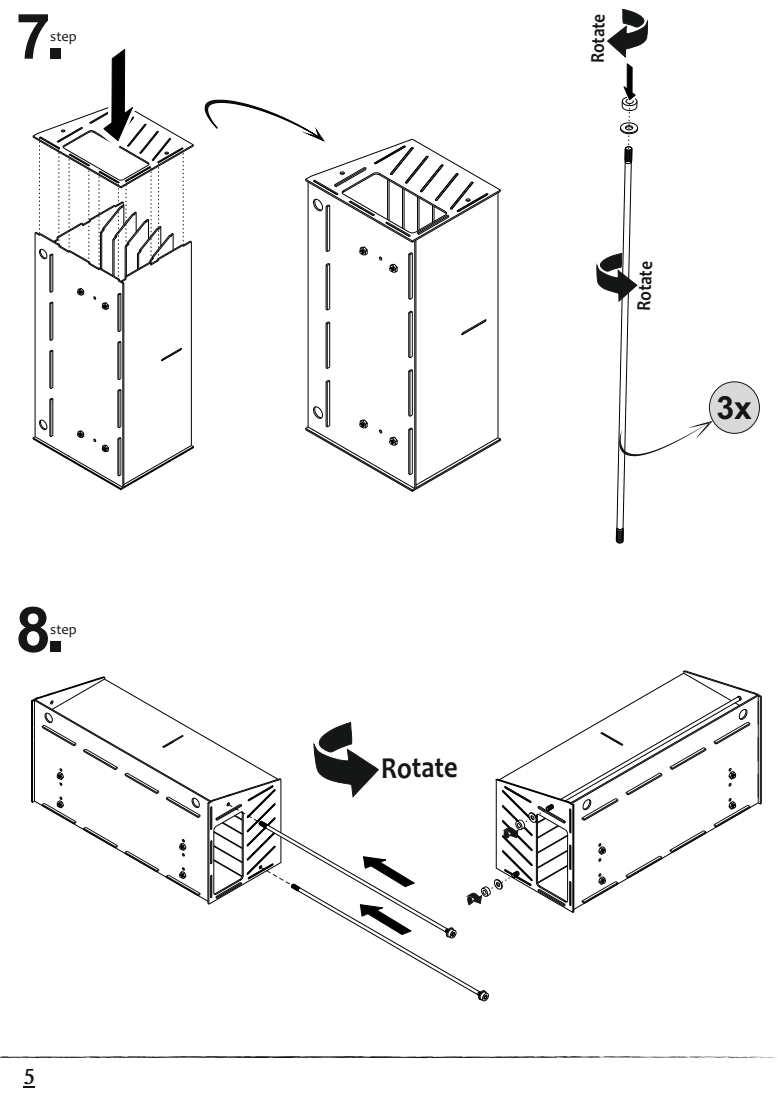
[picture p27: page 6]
Rotate; step; 8 step

9

step .

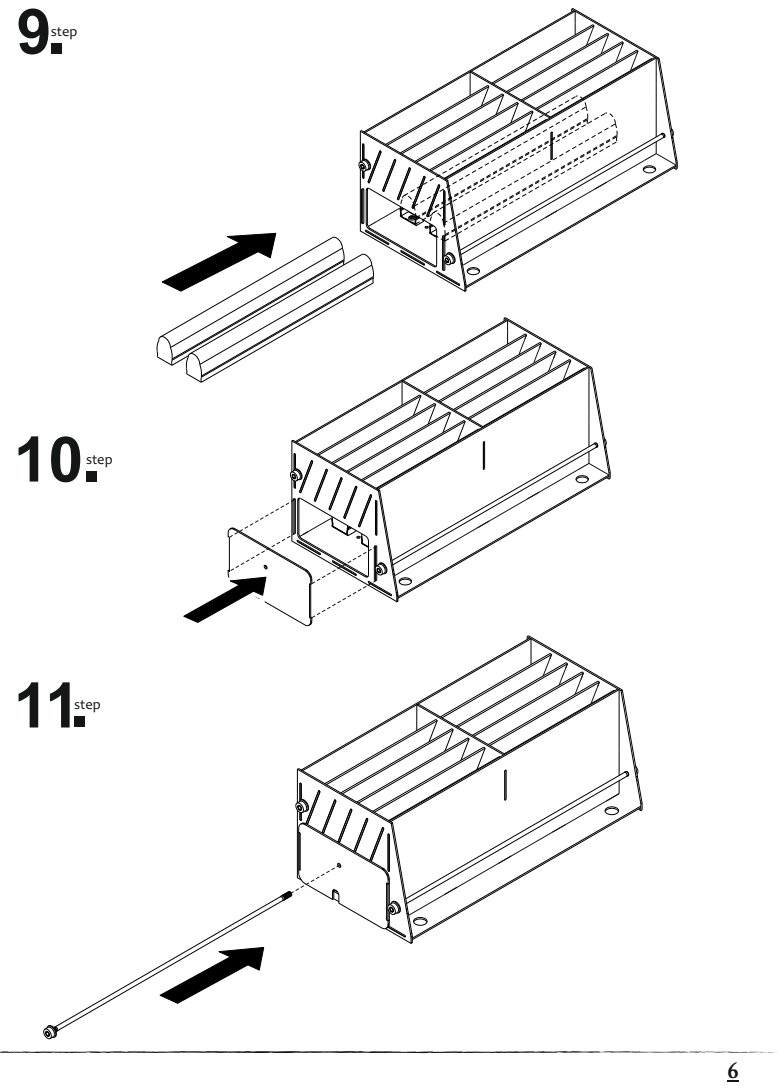
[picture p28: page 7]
10step . 11; step .

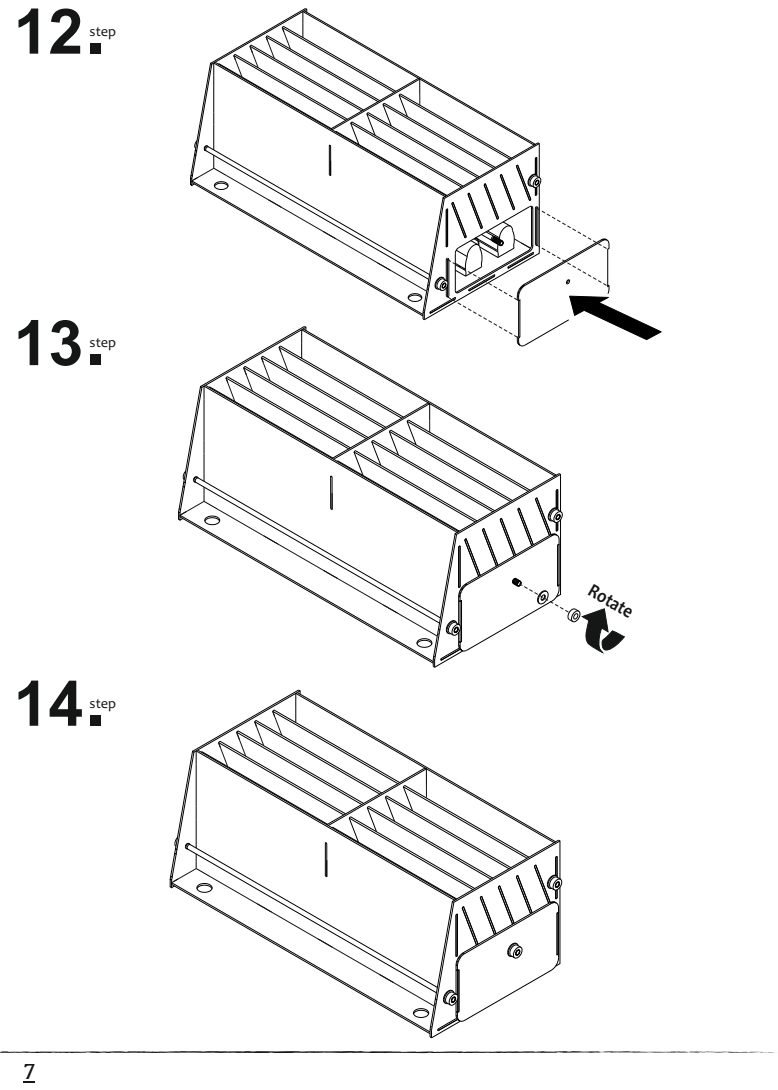
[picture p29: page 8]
Rotate; 12step; 13step; 14step

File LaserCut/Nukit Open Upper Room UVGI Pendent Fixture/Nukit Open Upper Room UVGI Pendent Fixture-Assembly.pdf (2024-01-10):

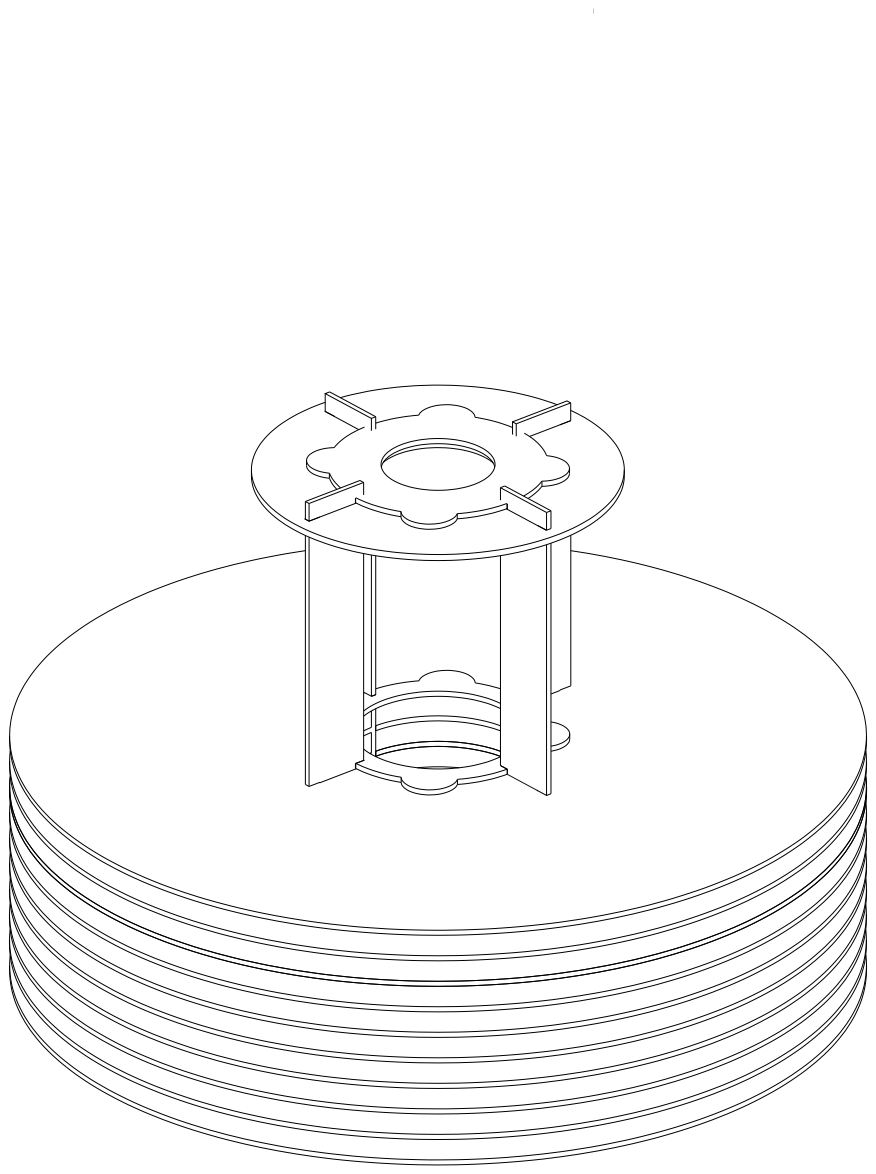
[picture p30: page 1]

1x

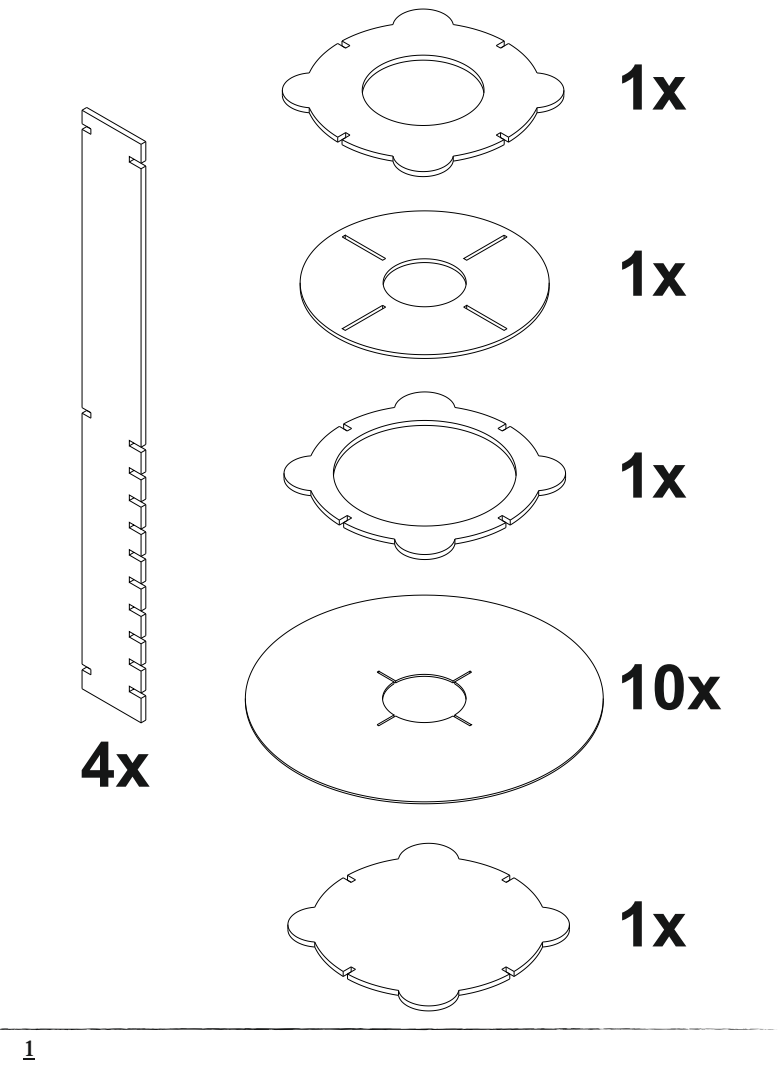
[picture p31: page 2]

1

. | 2

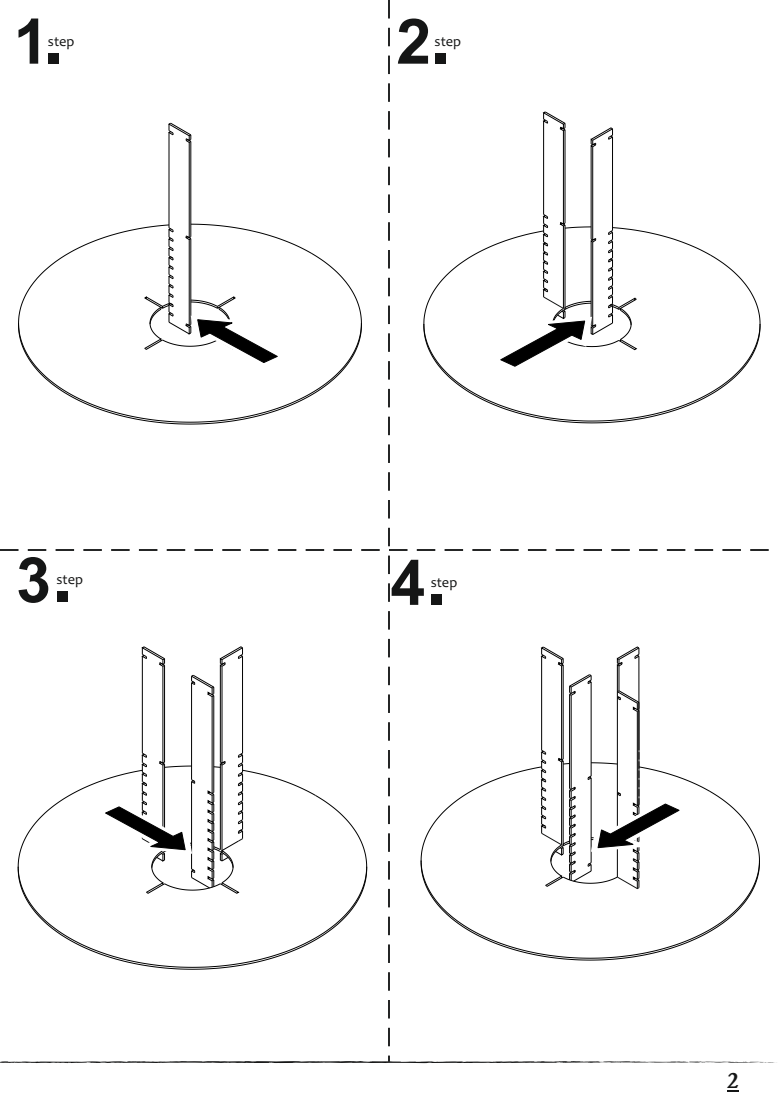
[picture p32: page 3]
step

5

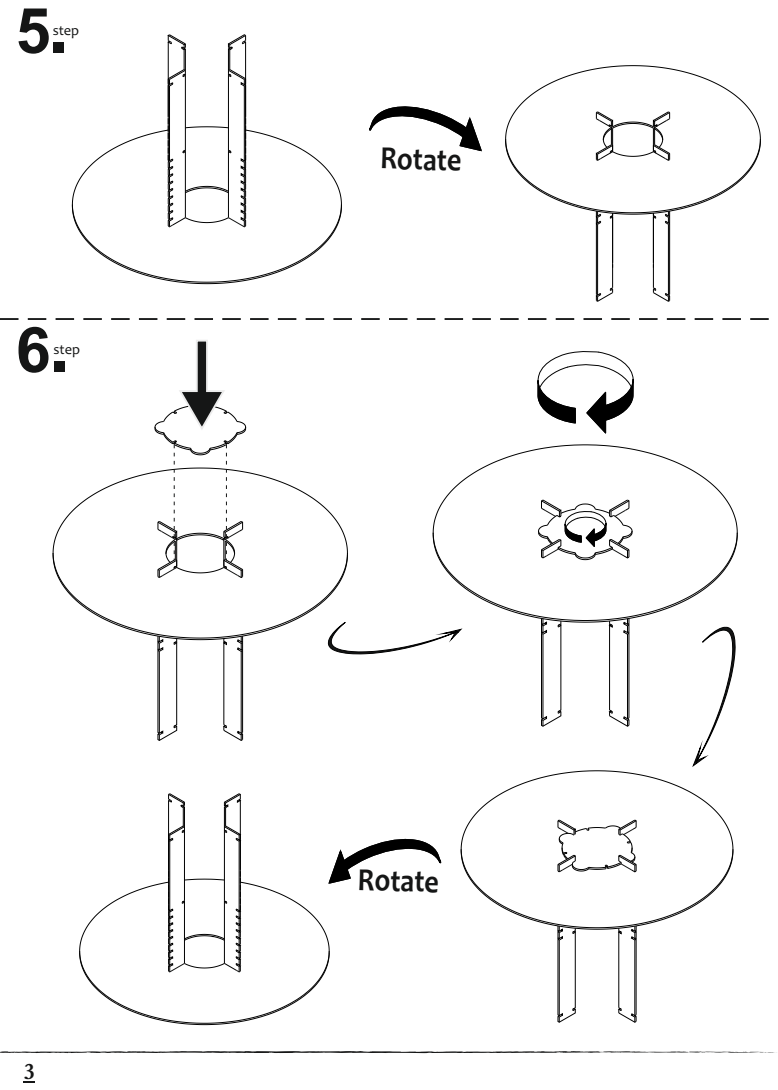
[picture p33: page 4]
Rotate; step

7

. | 8

step

. | 11

10step; 12step

13step; 14step

15step; 16step
